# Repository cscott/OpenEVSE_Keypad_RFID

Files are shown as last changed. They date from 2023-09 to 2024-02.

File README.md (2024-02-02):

# OpenEVSE Capacitive keypad and RFID reader

Thing tracker at
https://cscott.github.io/thing-tracker/#/thing/c6539aa6-b8c7-4adf-a22c-1baba5bbef97

There is a [Hackaday page for this project].

Discussion in the OpenEVSE forum at
https://openev.freshdesk.com/support/discussions/topics/6000067515

## Description

This repository contains hardware design files for a capacitive
keypad and RFID reader for [OpenEVSE] hardware.

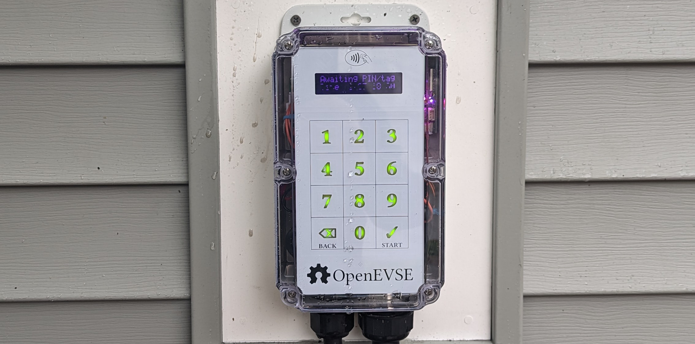
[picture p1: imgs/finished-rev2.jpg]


More details can be found on the
[Hackaday page for this project].

<br clear="both" />

## Instructions

### Step 1: Purchase components

You will need to purchase a new
[Polycase ML-58 enclosure](https://www.polycase.com/ml-58f), although
the only part we will need from it is the clear front cover.  (Perhaps
we can arrange a special purchase of just the cover if demand
warrants.)

You will also need to purchase or have the Keypad PCB fabricated.  The
KiCad design files are in the [`Keypad-Front`](./Keypad-Front)
subdirectory. It's a four-layer PCB, and I recommend white silkscreen
to avoid heating when in direct sun.  I used 1oz copper on a standard
1.6mm thick PCB.  I found that [JLCPCB](https://jlcpcb.com/) had
very reasonable prices.

I assume you also own an
[OpenEVSE Advanced Series](https://store.openevse.com/collections/all-products)
and have assembled it.

You will also need an LCD mount, which can be 3d printed.  You *might*
be able to reuse the one from your existing OpenEVSE device, but
you'll need to pry the glue off then cut down the top bar. It's
probably easier just to print a new one.

[`lcd-trim-more.stl`]

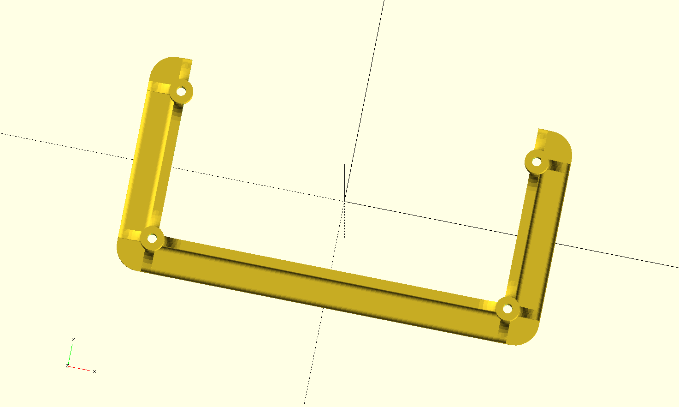
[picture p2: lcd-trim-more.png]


For compatibility with the latest OpenEVSE web interface, you will
also need to update the firmware on your main OpenEVSE controller
board.  This is out of scope for this guide, but you can find
instructions HERE.  It's a good thing to do between step 3 and 4
when you have your OpenEVSE charger disconnected and open.

### Step 2: Purchase or fabricate I2C cable

You will also need an I2C cable from the OpenEVSE Wifi board.  If you
have the latest-generation WiFi board, this will be a STEMMA-QT cable
(JST-SH, with 1.0mm pitch).  Older boards had an 8-pin JST-PH
connector (2.0mm pitch) and you will have to fabricate an adapter
yourself.

TODO: photos here

### Step 3: Remove cover from OpenEVSE

Unplug your OpenEVSE.  Don't try to do this with your OpenEVSE still
connected to mains power!

Remove the old printed blue cover from your OpenEVSE.  Disconnect
the cable leading from the OpenEVSE main board to the LCD display.

TODO: photo here.

### Step 4: Move the LCD module

Unscrew the LCD module from your old device and screw it onto the new
LCD mount.  You will then need to attach the new LCD mount to the
Keypad PCB, using the silkscreen as a guide.  I found that hot glue
worked well, but other adhesives are probably fine as well.

TODO: photo here

### Step 5: Mount the new PCB

You will now attach the Keypad PCB to the inside of your new clear
ML-58 enclosure cover.  I found that placing the board inside
the cover and then using generous drops of hot glue around the
screw bosses secured the Keypad PCB in a reversible manner, so that I
could still remove it if I needed to later.

TODO: photo here

If you're braver, a clear contact-sensitive adhesive tape (3M
makes a number of different types) would make a more permanent
bond.  Eliminating the air gap between the front cover and the
Keypad PCB is said to yield better performance from capacitive touch
sensors, but the hot-glue method has worked well enough for me.

### Step 5: Connect cables

You will need to connect two cables:

1. The LCD cable that you removed in step 3.

TODO: photo here

2. The I2C cable from step 2, from the OpenEVSE Wifi board to the
STEMMA-QT-compatible ports on the Keypad PCB.

TODO: photo here

### Step 6: Reattach the cover

Screw the cover back on the OpenEVSE!

TODO: photo here

### Step 7: Update OpenEVSE firmware

You'll need to reflash the OpenEVSE to the latest firmware.  The
good news is that you can do this over the web interface!

TODO: instructions here

### Step 8: Add some PINs and cards

TODO: instructions here

### Step 9: Optional improvements

The Keypad PCB also contains an MCP9808 temperature sensor and pads
for a DS3231MZ real-time clock.  Some older versions of the OpenEVSE
hardware contained an MCP9808 daisy-chained from the LCD module and
secured to the front cover.  If your hardware is like this, then
you can use the MCP9808 on the board by connecting the LCD display
to this port on the keypad PCB:

TODO: photo here

You should be able to use your existing cable, but if you have to
purchase or fabricate a new one, it's a STEMMA-QT compatible JST-SH
(1.0mm pitch) on the Keypad PCB side.  On my example, it was JST-PH
(2.0mm pitch) on the LCD side, and you can [buy an appropriate cable
from Adafruit](https://www.adafruit.com/product/4424).

Similarly, *newer* versions of the OpenEVSE hardware omit the
real-time clock which was present on the original OpenEVSE LCD modules.
The justification is that, with ubiquitous network connectivity,
you don't need to pay the steep price (~$10) for a clock chip when
instead you can just ask the network what time it is.

However, if you have intermittent network connectivity at your
installation site, you might want the peace of mind of knowing that
your usage timestamps will always be correct.  Because the RTC chip
is not cheap, it is not populated on the keypad PCB by default,
although all of its support components are present.  You can buy
an appropriate chip ([Digikey part link](https://www.digikey.com/en/products/detail/analog-devices-inc-maxim-integrated/DS3231MZ/2754396))
and battery connector ([Digikey part link](https://www.digikey.com/en/products/detail/mpd-memory-protection-devices/BC-2003-TR/5027929))
and hand-solder them onto the footprints provided.  While you've got
the soldering iron hot, you will most likely want to *remove* the
MCP9808 chip present on the Keypad PCB, since as far as I'm aware
all of the LCD modules *missing* the RTC *also* have the MCP9808
already present on the LCD board.  You don't want two MCP9808s trying
to talk on the same I2C bus.

After adding the RTC, you'd connect the I2C cable from the LCD
module to the Keypad PCB just as done for the MCP9808 above.

## Related

* [OpenEVSE] project
* [Hackaday page for this project]

## License

These designs are licensed under the [CC-BY-SA-4.0] like the original
OpenEVSE designs.

[OpenEVSE]: https://www.openevse.com/
[Hackaday page for this project]: https://hackaday.io/project/194656-openevse-capacitive-keypad-rfid
[`lcd-trim-more.stl`]: ./lcd-trim-more.stl
[CC-BY-SA-4.0]: https://spdx.org/licenses/CC-BY-SA-4.0.html

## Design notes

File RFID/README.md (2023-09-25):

Using
https://www.rfwireless-world.com/calculators/NFC-rectangular-antenna-calculator.html

99mm x 49mm (outer diam)
0.4mm track width, 0.4mm track gap
0.035mm track thickness (1oz copper)
2 turns
Fitting parameter E 1.65 ?

Inductance: 1.0055453920504143 uH
Equivelant conductor diameter: 0.13351167994874863 mm
Average length: 97.41314079732774 mm
Average width: 47.426996531511456 mm
-------------------
Tweaked:
45.6 mm x 98.8 mm
--------------
https://www.st.com/resource/en/application_note/cd00221490-how-to-design-a-13-56-mhz-customized-antenna-for-st25-nfc-rfid-tags-stmicroelectronics.pdf
https://www.nxp.com/docs/en/nxp/data-sheets/PN532_C1.pdf
https://www.nxp.com/docs/en/nxp/application-notes/153710.pdf
https://www.nxp.com/docs/en/nxp/application-notes/AN133910.pdf
https://www.nxp.com/products/rfid-nfc/nfc-hf/nfc-readers/nfc-integrated-solution:PN5321A3HN

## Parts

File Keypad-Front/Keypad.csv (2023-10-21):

Id | Designator | Footprint | Quantity | Designation | Supplier and ref
1 | TP12 | Touch_Pad_D1.0mm | 1 | KEY ENTER
2 | TP8 | Touch_Pad_D1.0mm | 1 | KEY 8
3 | TP7 | Touch_Pad_D1.0mm | 1 | KEY 7
4 | TP4 | Touch_Pad_D1.0mm | 1 | KEY 4
5 | TP9 | Touch_Pad_D1.0mm | 1 | KEY 9
6 | TP3 | Touch_Pad_D1.0mm | 1 | KEY 3
7 | TP5 | Touch_Pad_D1.0mm | 1 | KEY 5
8 | TP6 | Touch_Pad_D1.0mm | 1 | KEY 6
9 | TP11 | Touch_Pad_D1.0mm | 1 | KEY 0
10 | TP10 | Touch_Pad_D1.0mm | 1 | KEY BACK
11 | TP2 | Touch_Pad_D1.0mm | 1 | KEY 2
12 | TP1 | Touch_Pad_D1.0mm | 1 | KEY 1
13 | U4 | HVQFN-40-1EP_6x6mm_P0.5mm_EP4.1x4.1mm | 1 | PN5321A3HN_C1xx
14 | FB2,FB1 | R_0805_2012Metric_Pad1.20x1.40mm_HandSolder | 2 | FerriteBead_Small
15 | C3,C2 | C_0805_2012Metric_Pad1.18x1.45mm_HandSolder | 2 | 33pF
16 | D12,D1,D4,D8,D2,D11,D10,D3,D9,D5,D6,D7 | SunLED_3.2x2.8mm_ReverseMount | 12 | LED
17 | C1,C4 | C_0805_2012Metric_Pad1.18x1.45mm_HandSolder | 2 | 0.1uF
18 | Y3 | Crystal_SMD_TXC_7M-4Pin_3.2x2.5mm_HandSoldering | 1 | 27.12MHz
19 | R18,R17,R20 | R_0805_2012Metric_Pad1.20x1.40mm_HandSolder | 3 | 10k
20 | R6,R1,R3,R4,R11,R10,R16,R7,R8,R5,R12,R9,R2 | R_1206_3216Metric_Pad1.30x1.75mm_HandSolder | 13 | 100
21 | U5 | MSOP-8_3x3mm_P0.65mm | 1 | MCP9808_MSOP
22 | C9,C10,C14 | C_0805_2012Metric_Pad1.18x1.45mm_HandSolder | 3 | 10uF
23 | U3 | QFN-32-1EP_5x5mm_P0.5mm_EP3.3x3.3mm_ThermalVias | 1 | CAP1214
24 | JP1 | SolderJumper-3_P1.3mm_Bridged12_Pad1.0x1.5mm | 1 | SEL0
25 | R28,R29,R15,R30,R27 | R_0805_2012Metric_Pad1.20x1.40mm_HandSolder | 5 | 0
26 | R21,R22 | R_0805_2012Metric_Pad1.20x1.40mm_HandSolder | 2 | 1.5
27 | U1 | SOIC-8_3.9x4.9mm_P1.27mm | 1 | DS3231MZ
28 | J7 | JST-SH-4-VERT-SMD | 1 | TOUCH QWIIC
29 | R26 | R_0805_2012Metric_Pad1.20x1.40mm_HandSolder | 1 | 1.0k
30 | C13,C6,C7,C15,C26,C8,C11 | C_0805_2012Metric_Pad1.18x1.45mm_HandSolder | 7 | .1uF
31 | R25 | R_0805_2012Metric_Pad1.20x1.40mm_HandSolder | 1 | 2.7k
32 | BT1 | BatteryHolder_MPD_BC2003_1x2032 | 1 | Battery_Cell
33 | C18,C12,C24,C23 | C_0805_2012Metric_Pad1.18x1.45mm_HandSolder | 4 | N/C
34 | L1,L2 | L_0805_2012Metric_Pad1.15x1.40mm_HandSolder | 2 | 560nH
35 | C5 | C_0805_2012Metric_Pad1.18x1.45mm_HandSolder | 1 | 47pF
36 | R13,R19,R14 | R_0805_2012Metric_Pad1.20x1.40mm_HandSolder | 3 | 4.7k
37 | C19,C20 | C_0805_2012Metric_Pad1.18x1.45mm_HandSolder | 2 | 22pF
38 | C16,C17 | C_0805_2012Metric_Pad1.18x1.45mm_HandSolder | 2 | 220pF
39 | JP2 | SolderJumper-3_P1.3mm_Bridged12_Pad1.0x1.5mm | 1 | SEL1
40 | R23,R24 | SolderJumper-2_P1.3mm_Bridged_Pad1.0x1.5mm | 2 | N/C
41 | C21,C22 | C_0805_2012Metric_Pad1.18x1.45mm_HandSolder | 2 | 100pF
42 | J6 | JST-SH-4-VERT-SMD | 1 | EXP QWIIC
43 | C25 | C_0805_2012Metric_Pad1.18x1.45mm_HandSolder | 1 | 1000pF
44 | J1 | JST-SH-4-VERT-SMD | 1 | RTC STEMMA QT
45 | BZ1 | XDCR_SMT-1220-TW-R | 1 | Buzzer

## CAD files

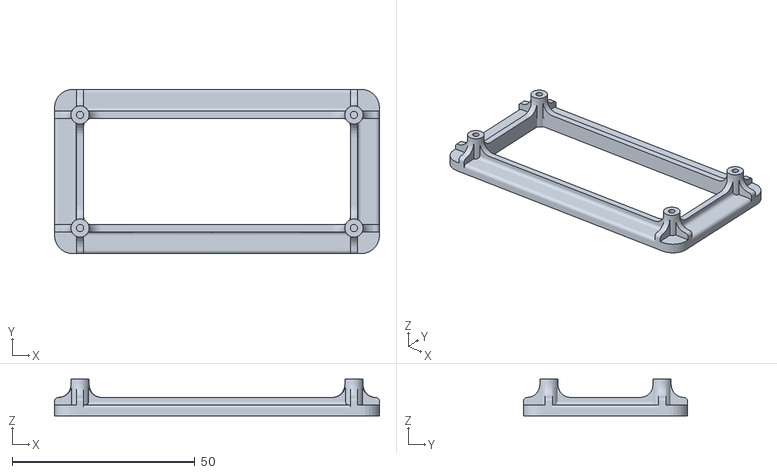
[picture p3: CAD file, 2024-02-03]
LCD_fixed.stl
89.0 x 45.0 x 10.0

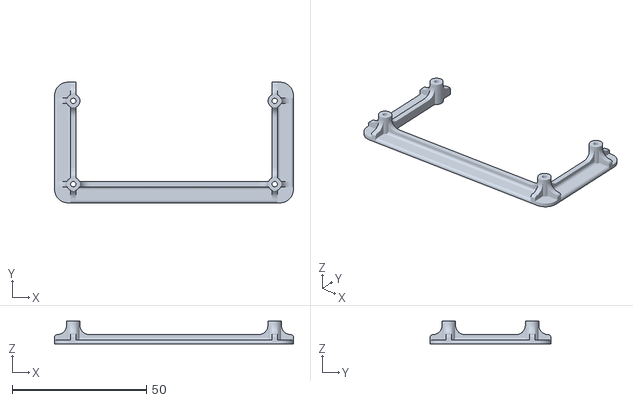
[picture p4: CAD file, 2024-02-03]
lcd-trim-more.stl
89.0 x 45.0 x 8.40

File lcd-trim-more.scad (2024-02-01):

cutoff=1.6;
difference() {
  intersection() {
    import("LCD_fixed.stl", convexity=5);
    translate([0,0,50 + cutoff]) cube([1000,1000,100], center=true);
  }
  difference() {
   translate([0,25,0]) cube([73,50,30], center=true);
   for (i=[-1,1]) {
     translate([i*75/2,15.5,0]) cylinder(d=5, h=30, $fn=20, center=true);
   }
  }
  for (i=[-1,1]) {
  for (j=[-1,1]) {
    translate([i*75/2,j*15.5,0]) cylinder(d=2, h=30, $fn=20, center=true);
  }
  }
}

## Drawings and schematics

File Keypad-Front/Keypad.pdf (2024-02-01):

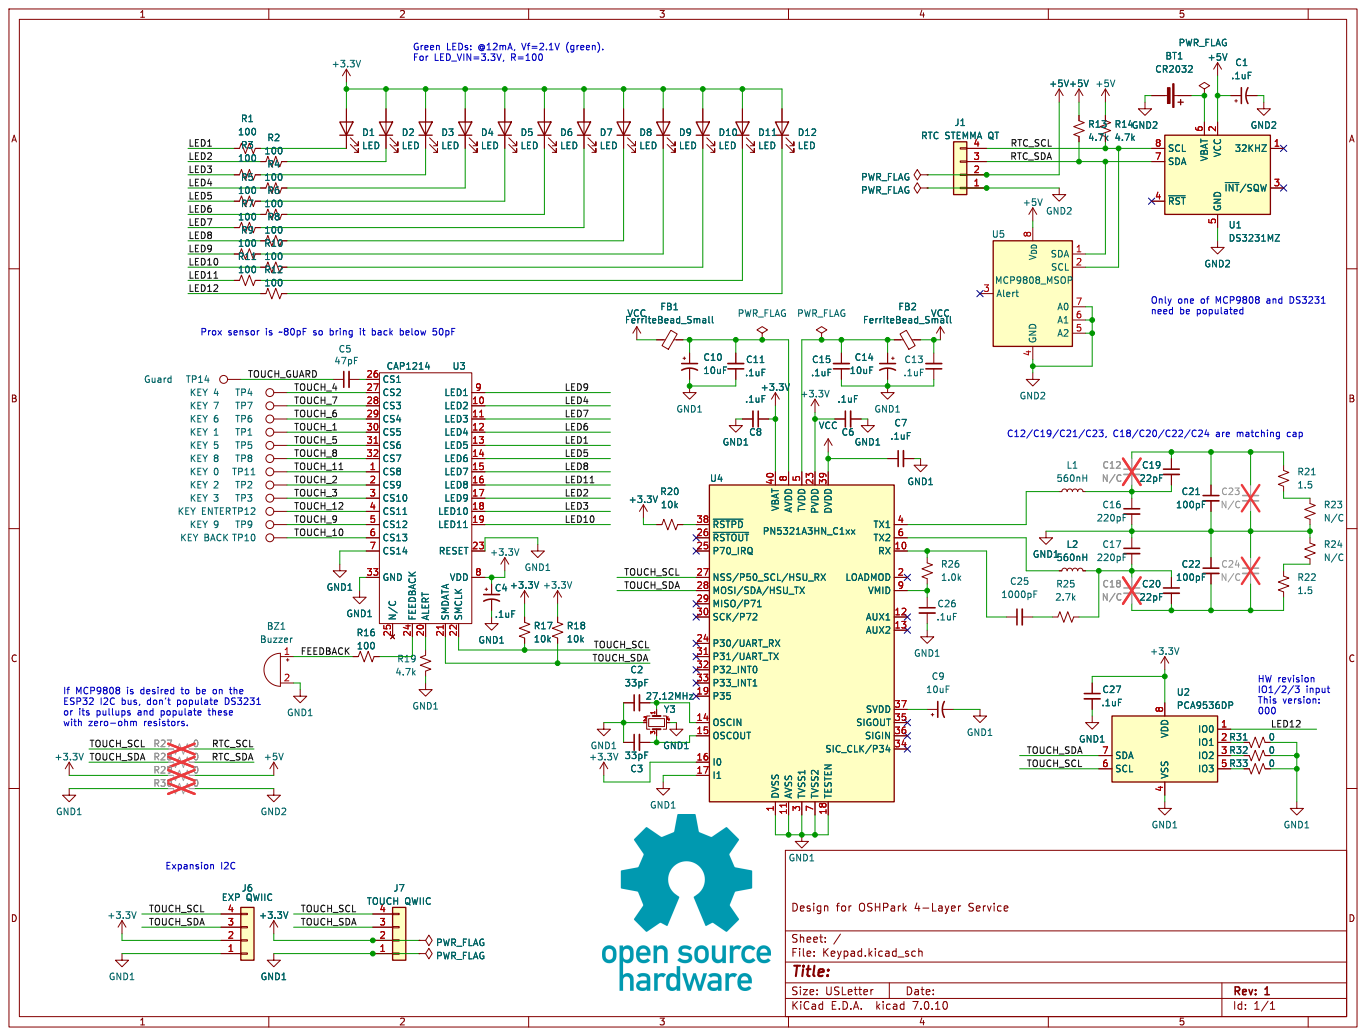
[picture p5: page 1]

3 SCK/P72 30 P31/UART_TX 31 P32_INT0 32 P33_INT1 33 SIC_CLK/P34 34 SIGOUT 35 SIGIN 36 SVDD 37 ~{RSTPD} 38 DVDD 39 TX1 4 VBAT 40 TVDD

1 RX 10 AVSS 11 AUX1 12 AUX2 13 OSCIN 14 OSCOUT 15

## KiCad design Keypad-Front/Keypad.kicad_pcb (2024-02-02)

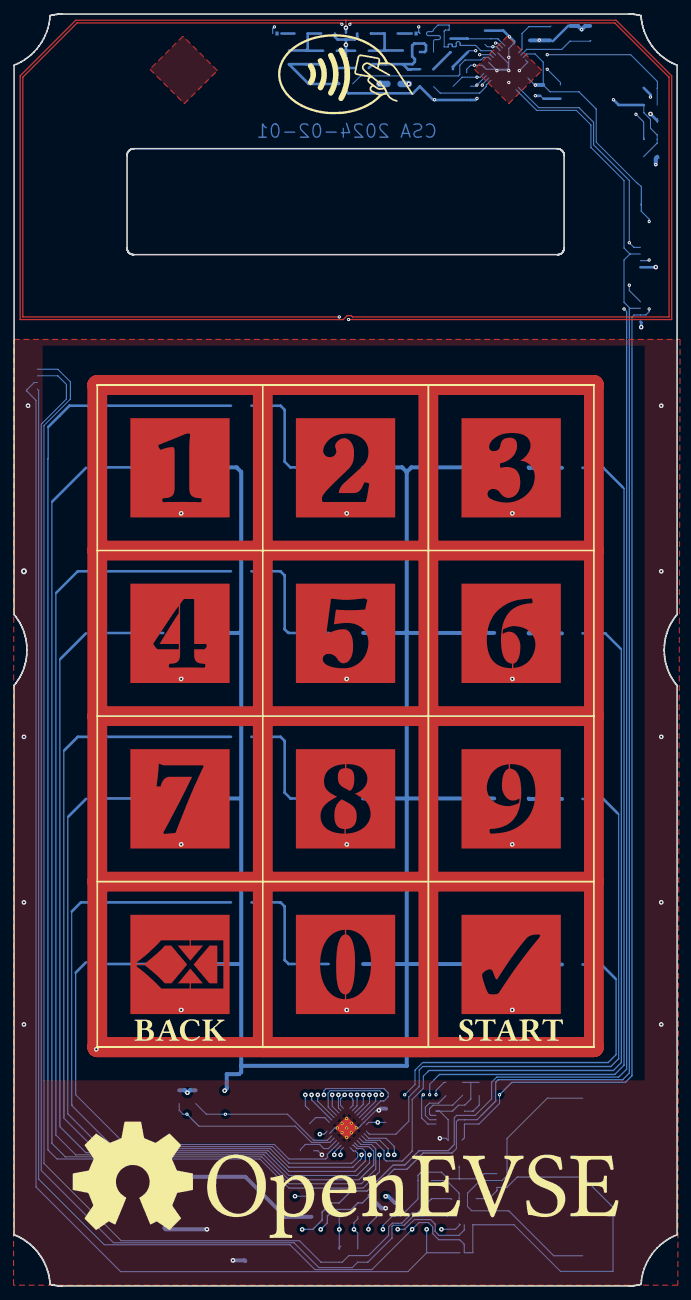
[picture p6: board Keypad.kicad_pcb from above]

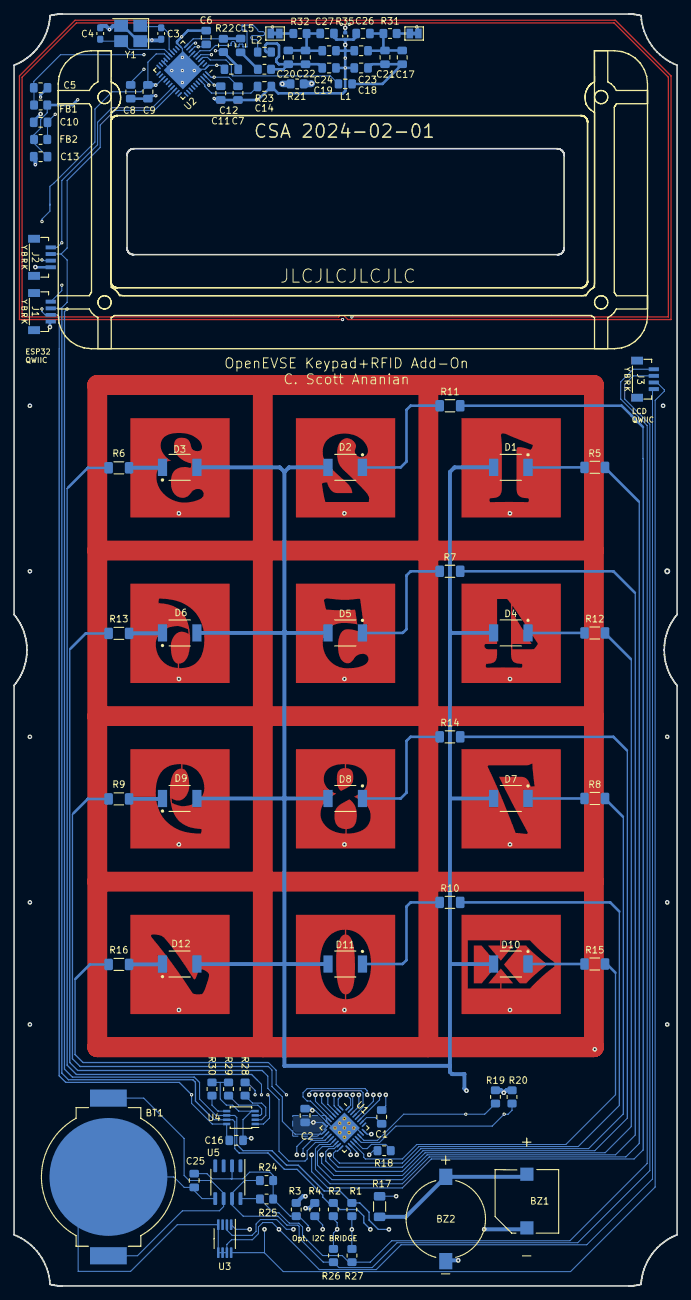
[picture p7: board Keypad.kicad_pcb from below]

Board: 4 copper layers, 100.1 x 192.1 mm, 103 parts (90 on the bottom side), 74 nets.

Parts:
BT1: CR2032; BatteryHolder_MPD_BC2003_1x2032
BZ1: FUET-9650B-3V
BZ2: PUI SMT-1220-TW-R; XDCR_SMT-1220-TW-R
C1: 47pF; C_0805_2012Metric_Pad1.18x1.45mm_HandSolder
C2, C6, C7, C8, C9, C11, C12, C13, C16, C25: .1uF; C_0805_2012Metric_Pad1.18x1.45mm_HandSolder
C3, C4: 33pF; C_0603_1608Metric_Pad1.08x0.95mm_HandSolder
C5, C10, C14: 10uF; C_0805_2012Metric_Pad1.18x1.45mm_HandSolder
C15: 1000pF; C_0805_2012Metric_Pad1.18x1.45mm_HandSolder
C17, C20, C26, C27: N/C; C_0805_2012Metric_Pad1.18x1.45mm_HandSolder
C18, C19: 220pF; C_0805_2012Metric_Pad1.18x1.45mm_HandSolder
C21, C22: 22pF; C_0805_2012Metric_Pad1.18x1.45mm_HandSolder
C23, C24: 100pF; C_0805_2012Metric_Pad1.18x1.45mm_HandSolder
D1, D2, D3, D4, D5, D6, D7, D8, D9, D10, D11, D12: SunLED XZVG45WT-9; SunLED_3.2x2.8mm_ReverseMount
FB1, FB2: Laird MI0805J102R-10; R_0805_2012Metric_Pad1.20x1.40mm_HandSolder
J1: EXP QWIIC; JST-SH-4-VERT-SMD
J2: TOUCH QWIIC; JST-SH-4-VERT-SMD
J3: RTC STEMMA QT; JST-SH-4-VERT-SMD
L1, L2: 560nH; L_0805_2012Metric_Pad1.15x1.40mm_HandSolder
R1, R2, R3, R4, R26, R27: 0; R_0805_2012Metric_Pad1.20x1.40mm_HandSolder
R5, R6, R7, R8, R9, R10, R11, R12, R13, R14, R15, R16, R17: 100; R_1206_3216Metric_Pad1.30x1.75mm_HandSolder
R18, R24, R25: 4.7k; R_0805_2012Metric_Pad1.20x1.40mm_HandSolder
R19, R20, R21: 10k; R_0805_2012Metric_Pad1.20x1.40mm_HandSolder
R22, R28, R29, R30: 1k; R_0805_2012Metric_Pad1.20x1.40mm_HandSolder
R23: 2.7k; R_0805_2012Metric_Pad1.20x1.40mm_HandSolder
R31, R32: 1.5; R_0805_2012Metric_Pad1.20x1.40mm_HandSolder
R33, R34: N/C; SolderJumper-2_P1.3mm_Bridged_Pad1.0x1.5mm
R35: 0; R_0402_1005Metric
TP1: Guard; Touch_Pad_D1.0mm
TP2: KEY 4; Touch_Pad_D1.0mm
TP3: KEY 7; Touch_Pad_D1.0mm
TP4: KEY 6; Touch_Pad_D1.0mm
TP5: KEY 1; Touch_Pad_D1.0mm
TP6: KEY 5; Touch_Pad_D1.0mm
TP7: KEY 8; Touch_Pad_D1.0mm
TP8: KEY 0; Touch_Pad_D1.0mm
TP9: KEY 2; Touch_Pad_D1.0mm
TP10: KEY 3; Touch_Pad_D1.0mm
TP11: KEY ENTER; Touch_Pad_D1.0mm
TP12: KEY 9; Touch_Pad_D1.0mm
TP13: KEY BACK; Touch_Pad_D1.0mm
U1: CAP1214; QFN-32-1EP_5x5mm_P0.5mm_EP3.3x3.3mm_ThermalVias
U2: PN5321A3HN_C1xx; HVQFN-40-1EP_6x6mm_P0.5mm_EP4.1x4.1mm
U3: MCP9808_MSOP; MSOP-8_3x3mm_P0.65mm
U4: PCA9536DP; TSSOP-8_3x3mm_P0.65mm
U5: DS3231MZ; SOIC-8_3.9x4.9mm_P1.27mm
Y1: 27.12MHz; Crystal_SMD_TXC_7M-4Pin_3.2x2.5mm_HandSoldering

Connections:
+3.3V: C2.1, C7.1, C9.1, C16.1, D1.2 (A), D2.2 (A), D3.2 (A), D4.2 (A), D5.2 (A), D6.2 (A), D7.2 (A), D8.2 (A), D9.2 (A), D10.2 (A), D11.2 (A), D12.2 (A), J1.2, J2.2, R3.1, R19.1, R20.1, R21.1, R28.2, U1.8 (VDD), U2.16 (I0), U2.23 (PVDD), U2.40 (VBAT), U4.8 (VDD)
+5V: C25.1, J3.2, R3.2, R24.1, R25.1, U3.8 (V_{DD}), U5.2 (VCC)
/FEEDBACK: BZ1.1 (+), BZ2.1 (+), R17.1
/FEED_N: C19.2, C20.1, C22.1, L2.2, R23.1
/FEED_P: C17.2, C18.1, C21.2, L1.2
/LED1: R5.1, U1.13 (LED5)
/LED2: R11.1, U1.17 (LED9)
/LED3: R6.1, U1.18 (LED10)
/LED4: R12.1, U1.10 (LED2)
/LED5: R7.1, U1.14 (LED6)
/LED6: R13.1, U1.12 (LED4)
/LED7: R8.1, U1.11 (LED3)
/LED8: R14.1, U1.15 (LED7)
/LED9: R9.1, U1.9 (LED1)
/LED10: R15.1, U1.19 (LED11)
/LED11: R10.1, U1.16 (LED8)
/LED12: R16.1, U4.1 (IO0)
/RTC_SCL: J3.4, R25.2, R27.1, U5.8 (SCL)
/RTC_SDA: J3.3, R24.2, R26.1, U5.7 (SDA)
/TEMP_SCL: R1.2, R27.2, U3.2 (SCL)
/TEMP_SDA: R2.2, R26.2, U3.1 (SDA)
/TOUCH_1: TP5.1, U1.30 (CS5)
/TOUCH_2: TP9.1, U1.2 (CS9)
/TOUCH_3: TP10.1, U1.3 (CS10)
/TOUCH_4: TP2.1, U1.27 (CS2)
/TOUCH_5: TP6.1, U1.31 (CS6)
/TOUCH_6: TP4.1, U1.29 (CS4)
/TOUCH_7: TP3.1, U1.28 (CS3)
/TOUCH_8: TP7.1, U1.32 (CS7)
/TOUCH_9: TP12.1, U1.5 (CS12)
/TOUCH_10: TP13.1, U1.6 (CS13)
/TOUCH_11: TP8.1, U1.1 (CS8)
/TOUCH_12: TP11.1, U1.4 (CS11)
/TOUCH_GUARD: C1.1, TP1.1
/TOUCH_SCL: J1.4, J2.4, R1.1, R19.2, U1.22 (SMCLK), U2.27 (NSS/P50_SCL/HSU_RX), U4.6 (SCL)
/TOUCH_SDA: J1.3, J2.3, R2.1, R20.2, U1.21 (SMDATA), U2.28 (MOSI/SDA/HSU_TX), U4.7 (SDA)
/TX_N: L2.1, U2.6 (TX2)
/TX_P: L1.1, U2.4 (TX1)
GND1: BZ1.2 (-), BZ2.2 (-), C2.2, C3.1, C4.1, C5.2, C6.1, C7.2, C8.1, C9.2, C10.2, C11.2, C12.2, C13.1, C14.2, C16.2, C18.2, C19.1, C23.2, C24.1, C26.2, C27.1, J1.1, J2.1, R4.1, R18.2, R29.2, R30.2, R35.1, U1.7 (CS14), U1.23 (RESET), U1.33 (GND), U2.1 (DVSS), U2.3 (TVSS1), U2.7 (TVSS2), U2.11 (AVSS), U2.17 (I1), U2.18 (TESTEN), U2.41 (AVSS), U4.4 (VSS), Y1.2, Y1.4
GND2: BT1.2 (-), C25.2, J3.1, R4.2, U3.4 (GND), U3.5 (A2), U3.6 (A1), U3.7 (A0), U5.5 (GND)
unnamed: BT1.1 (+), U5.6 (VBAT)
unnamed: C15.2, R23.2
unnamed: C17.1, C21.1, C23.1, C26.1, R31.2
unnamed: C20.2, C22.2, C24.2, C27.2, R32.1
unnamed: D1.1 (K), R5.2
unnamed: D2.1 (K), R11.2
unnamed: D3.1 (K), R6.2
unnamed: D4.1 (K), R12.2
unnamed: D5.1 (K), R7.2
unnamed: D6.1 (K), R13.2
unnamed: D7.1 (K), R8.2
unnamed: D8.1 (K), R14.2
unnamed: D9.1 (K), R9.2
unnamed: D10.1 (K), R15.2
unnamed: D11.1 (K), R10.2
unnamed: D12.1 (K), R16.2
unnamed: R31.1, R33.2
unnamed: R32.2, R34.1
unnamed: R33.1, R34.2, R35.2
unnamed: R18.1, U1.20 (ALERT)
unnamed: C1.2, U1.26 (CS1)
unnamed: R17.2, U1.24 (FEEDBACK)
unnamed: C5.1, C6.2, FB1.2, U2.8 (AVDD)
unnamed: C3.2, U2.14 (OSCIN), Y1.1
unnamed: C4.2, U2.15 (OSCOUT), Y1.3
unnamed: C15.1, R22.2, U2.10 (RX)
unnamed: C14.1, U2.37 (SVDD)
unnamed: C8.2, C10.1, FB2.2, U2.5 (TVDD)
unnamed: C12.1, R22.1, U2.9 (VMID)
unnamed: R21.2, U2.38 (~RSTPD)
unnamed: R28.1, U4.2 (IO1)
unnamed: R29.1, U4.3 (IO2)
unnamed: R30.1, U4.5 (IO3)
VCC: C11.1, C13.2, FB1.1, FB2.1, U2.39 (DVDD)

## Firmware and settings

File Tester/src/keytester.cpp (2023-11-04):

#if defined(KEYTESTER)

#define RTCTEST 1
#define TEMPTEST 1
#define RFIDTEST 1
//#define PROXTEST 1
//#define LEDTEST 1

#define BRIGHT_PAD 1
#define LONG_WAIT_AFTER_INIT

// Note that Capacitive sensing is significantly more sensitive when the
// system has a robust earth ground, which is the case when the OpenEVSE
// is installed but may not be the case if attempting to calibrate on a
// bench.

// Sensitivity is 0-15 with 15 being max sensitivity; each step is 2x
// sensitivity of previous step.
#define PROX_SENSITIVITY 15 /* when installed is 13 */
#define KEY_SENSITIVITY 14 /* when installed is 13 */

#ifdef BRIGHT_PAD
# define POLARITY_AWAKE 0xFF
# define POLARITY_ASLEEP 0x00
#else
# define POLARITY_AWAKE 0x00
# define POLARITY_ASLEEP 0xFF
#endif

#include "Arduino.h"
#include <Wire.h>
#include <AsyncDelay.h>

#include <ESP8266WiFi.h>
#include <WiFiClient.h>
#include <ESP8266mDNS.h>
#include <ArduinoOTA.h>

// includes for OLED display
#include <SPI.h>
#include <Wire.h>
#include <Adafruit_GFX.h>
#include <Adafruit_SH110X.h>

#include "cap1214-reg.h"
#include "config.h"
#define MDNS_NAME "keytester"

#define PCA9536_I2C_ADDR     0x41
#define PCA9536_REG_INPUT    0x00
#define PCA9536_REG_OUTPUT   0x01
#define PCA9536_REG_POLARITY 0x02
#define PCA9536_REG_CONFIG   0x03

#ifdef RFIDTEST
#include "Adafruit_PN532.h"
Adafruit_PN532 rfid(-1, -1, &Wire);
bool rfid_good = false;
#endif

#ifdef TEMPTEST
#include "Adafruit_MCP9808.h"
Adafruit_MCP9808 tempsensor = Adafruit_MCP9808();
bool tempsensor_good = false;
#endif

#ifdef RTCTEST
#include "RTClib.h"
RTC_DS3231 rtc;
char daysOfTheWeek[7][12] = {
  "Sun", "Mon", "Tue", "Wed", "Thu", "Fri", "Sat"
};
bool rtc_good = false;
#endif /* RTCTEST */
bool cap_good = false;
bool is_awake = true;
bool keypad_hw_v2 = false;
uint8_t polarity = 0;

// Configuration of OLED display
Adafruit_SH1107 display = Adafruit_SH1107(64, 128, &Wire);

// OLED FeatherWing buttons map to different pins depending on board:
#define BUTTON_A  0
#define BUTTON_B 16
#define BUTTON_C  2

// Other config
#define LED_GPIO 0
#define LED_OFF 1 // active low
#define LED_ON  0 // active low

AsyncDelay updateDelay = AsyncDelay(250, AsyncDelay::MILLIS);
AsyncDelay proxDelay = AsyncDelay(5000, AsyncDelay::MILLIS);
bool blinkWasOn = false;
bool mdns_success;

bool pca9536_write(uint8_t regno, uint8_t val) {
  Wire.beginTransmission(PCA9536_I2C_ADDR);
  Wire.write(regno);
  Wire.write(val);
  uint8_t status = Wire.endTransmission();
  if (status != 0) {
    return false;
  }
  return true;
}

bool pca9536_read(uint8_t regno, uint8_t *val) {
    Wire.beginTransmission(PCA9536_I2C_ADDR);
    Wire.write(regno);
    uint8_t status = Wire.endTransmission();
    if (status != 0) {
        return false;
    }
    uint8_t nBytes = Wire.requestFrom(PCA9536_I2C_ADDR, 1);
    if (nBytes == 0) {
        return false;
    }
    *val = Wire.read();
    return true;
}

int read_keypad_version() {
  // Configure to all inputs (also implicitly check to see whether it's present)
  if (!pca9536_write(PCA9536_REG_CONFIG, 0xFF)) { goto failed; }
  if (!pca9536_write(PCA9536_REG_POLARITY, 0x00)) { goto failed; }
  // Read the version pins!
  uint8_t version;
  if (!pca9536_read(PCA9536_REG_INPUT, &version)) { goto failed; }
  if ((version & 0x0E) == 0) {
    // this is version 1! First pin configure for output
    if (!pca9536_write(PCA9536_REG_OUTPUT, 0x01)) { goto failed; }
    if (!pca9536_write(PCA9536_REG_CONFIG, 0xFE)) { goto failed; }
    return 2; // Keypad HW v2
  }
  // Fall through -- this is an unrecognized version
 failed:
  return 1; // Keypad v1 didn't have a PCA9536
}

bool cap1214_write(uint8_t regno, uint8_t val) {
  Wire.beginTransmission(CAP1214_I2C_ADDR);
  Wire.write(regno);
  Wire.write(val);
  uint8_t status = Wire.endTransmission();
  if (status != 0) {
    return false;
  }
  return true;
}

bool cap1214_read(uint8_t regno, uint8_t *val) {
    Wire.beginTransmission(CAP1214_I2C_ADDR);
    Wire.write(regno);
    uint8_t status = Wire.endTransmission();
    if (status != 0) {
        return false;
    }
    uint8_t nBytes = Wire.requestFrom(CAP1214_I2C_ADDR, 1);
    if (nBytes == 0) {
        return false;
    }
    *val = Wire.read();
    return true;
}

bool cap1214_init(void) {
  uint8_t vendor_id, product_id, revision, build_rev;
  delay(20); // at least 20ms (tCOMM)
  if (!cap1214_read(CAP1214_REG_VENDOR_ID, &vendor_id)) { goto failed; }
  if (vendor_id != 0x5D) { goto failed; }
  if (!cap1214_read(CAP1214_REG_PRODUCT_ID, &product_id)) { goto failed; }
  if (product_id != 0x5A) { goto failed; }
  if (!cap1214_read(CAP1214_REG_REVISION, &revision)) { goto failed; }
  if (revision != 0x80) { goto failed; }
  if (!cap1214_read(CAP1214_REG_BUILD_REVISION, &build_rev)) { goto failed; }
  if (build_rev != 0x10) { goto failed; }
  // Activate LEDs and scanning
  cap1214_write(CAP1214_REG_MAIN_STATUS, 0x00);
  cap1214_write(CAP1214_REG_CONFIGURATION, 0x2A);// enable recal on grouped sens, disable repeat rate
  cap1214_write(CAP1214_REG_CONFIGURATION_2, 0x02); // *not* VOL_UP_DOWN
  cap1214_write(CAP1214_REG_GROUP_CONFIGURATION_1, 0x40); // zero out M_PRESS (CS8)
  cap1214_write(CAP1214_REG_SENSOR_ENABLE, 0xFF);
  cap1214_write(CAP1214_REG_GROUPED_CHANNEL_SENSOR_ENABLE, 0x3F); // disable CS14
  // Increase general sensitivity
  cap1214_write(CAP1214_REG_DATA_SENSITIVITY, 0x0F + 16*(15-KEY_SENSITIVITY)); // 64x sensitivity
  cap1214_write(CAP1214_REG_PROXIMITY_CONTROL, 0x80 + (15-PROX_SENSITIVITY)); // CS1 is prox, max sens
  // allow independent configuration of CS1 threshold
  cap1214_write(CAP1214_REG_RECALIBRATION_CONFIGURATION, 0x13); // !BUT_LD_TH
  // 256ms, 2kHz 110 01000
  cap1214_write(CAP1214_REG_FEEDBACK_CONFIGURATION, 0xC8); // 256ms, 2kHz
  // Everything triggers feedback, but CS1, CS8, and CS14
  // (CS8 has a weird press-and-hold misfeatures that triggers feedback
  // before the actual press is registered in the queue.)
  cap1214_write(CAP1214_REG_FEEDBACK_CHANNEL_CONFIGURATION_1, 0x7E);
  cap1214_write(CAP1214_REG_FEEDBACK_CHANNEL_CONFIGURATION_2, 0x3E);
  // Link the sensor LEDs CS2-CS7
  // - excluding CS1 because it is used for proximity
  // - excluding UP_DOWN_LINK
  if (keypad_hw_v2) {
    cap1214_write(CAP1214_REG_SENSOR_LED_LINKING, 0x7E);
  } else {
    // In v1 hardware, also:
    // - excluding CS4 for which we need manual control because it is paired
    cap1214_write(CAP1214_REG_SENSOR_LED_LINKING, 0x76);
  }
  // LED/GPIO pins are outputs!
  cap1214_write(CAP1214_REG_LED_GPIO_DIRECTION, 0xFF); // LED1-LED8 = output
  // flip polarity of all LEDs (normally off, to keep power low)
  polarity = POLARITY_ASLEEP;
  cap1214_write(CAP1214_REG_LED_POLARITY_1, polarity);
  cap1214_write(CAP1214_REG_LED_POLARITY_2, polarity);

  // disable multiple touch suppression (since PROX aka CS1 sets it off)
  cap1214_write(CAP1214_REG_MULTIPLE_PRESS_CONFIGURATION, 0x00);
#if 1
  // Improve responsiveness: by default we need 3 readings over threshold;
  // change to 1 to make things a bit snappier.
  cap1214_write(CAP1214_REG_QUEUE_CONTROL, 0x01);
#else
  // Reducing sample time by 50% doesn't seem to have the same effect
  // (probably because we're dominated by prox sampling time?)
  cap1214_write(CAP1214_REG_QUEUE_CONTROL, 0x02);
  cap1214_write(CAP1214_REG_SAMPLING_CHANNEL_SELECT, 0xFF);
  cap1214_write(CAP1214_REG_SAMPLING_CONFIGURATION, 0x01); // 1.28ms sampling time
#endif

#ifdef PROXTEST
  // disable all except for CS1 (prox)
  cap1214_write(CAP1214_REG_SENSOR_ENABLE, 0x01);
  cap1214_write(CAP1214_REG_PROXIMITY_CONTROL, 0x88);
  cap1214_write(CAP1214_REG_FEEDBACK_CHANNEL_CONFIGURATION_1, 0x01);
  cap1214_write(CAP1214_REG_FEEDBACK_CHANNEL_CONFIGURATION_2, 0x00);
  cap1214_write(CAP1214_REG_DATA_SENSITIVITY, 0x1F); // 8x sensitivity
#endif

#ifdef LEDTEST
  cap1214_write(CAP1214_REG_SENSOR_LED_LINKING, 0x00);
  for (uint8_t i=0; i<8; i++) {
    cap1214_write(CAP1214_REG_LED_OUTPUT_CONTROL_1, 1<<i);
    cap1214_write(CAP1214_REG_FEEDBACK_ONESHOT, 0xFF);
    delay(1000);
  }
  cap1214_write(CAP1214_REG_LED_OUTPUT_CONTROL_1, 0);
  for (uint8_t i=0; i<3; i++) {
    cap1214_write(CAP1214_REG_LED_OUTPUT_CONTROL_2, 1<<i);
    cap1214_write(CAP1214_REG_FEEDBACK_ONESHOT, 0xFF);
    delay(1000);
  }
  cap1214_write(CAP1214_REG_LED_OUTPUT_CONTROL_2, 0);
  cap1214_write(CAP1214_REG_SENSOR_LED_LINKING, 0x7E);
#endif

  // recalibrate all
  //cap1214_write(CAP1214_REG_DIGITAL_RECALIBRATION, 0xFF);
  return true;

 failed:
  return false;
}

uint16_t cap1214_read_buttons(bool clear = true) {
  uint8_t st1 = 0, st2 = 0, st3 = 0;
  cap1214_read(CAP1214_REG_BUTTON_STATUS_1, &st1);
  cap1214_read(CAP1214_REG_BUTTON_STATUS_2, &st2);
  cap1214_read(CAP1214_REG_GROUP_STATUS, &st3); // clears TAP
  if (clear) {
    // clear the latched button status by clearing INT!
    cap1214_write(CAP1214_REG_MAIN_STATUS, 0x00);
  }

  // merge
  uint16_t merged = (st1 & 0x3F); // zero out UP & DOWN
  merged |= (((uint16_t)st2) << 6); // Add in high order bits at the right place
  // account for tap and hold logic on CS8 (CS14 is unused)
  if (st3 & 0xF) { merged |= 0x80; }

#define merged_cs(x) (merged & (((uint16_t)1)<<(x-1)))
  // manually set feedback pins for CS8-CS13
  // CS8/9/10 -> LED8/9/10
  uint8_t led1 = 0, led2 = 0, led3 = 0;
  static bool saw_cs8 = false;
  if (merged_cs(8)) { // CS8 (touch 11, key 0)
    led1 |= 0x80;
    // Need to manually trigger feedback, because if we link this automatically
    // feedback will be triggered for touches too short to actually register
    // in the button queue.
    if (!saw_cs8) {
      cap1214_write(CAP1214_REG_FEEDBACK_ONESHOT, 0xFF);
      saw_cs8 = true;
    }
  } else {
    saw_cs8 = false;
  }
  if (merged_cs(9)) { // CS9 (touch 2)
    led2 |= 0x01; // LED 9
  }
  if (merged_cs(10)) { // CS10 (touch 3)
    led2 |= 0x02; // LED 10
  }
  if (keypad_hw_v2) {
    // CS11 & CS13 -> LED11/LED12 (expansion)
    if (merged_cs(13)) { // CS13 (touch 10, key backspace)
      led2 |= 0x04; // LED 11
    }
    if (merged_cs(11)) { // CS11 (touch 12, key enter)
      led3 |= 0x01; // LED 12
    }
  } else {
    // CS4 & CS11 -> LED4
    if (merged_cs(4)) { // CS4 (touch 10, key backspace)
      led1 |= 0x08; // LED 4
    }
    if (merged_cs(11)) { // CS11 (touch 12, key enter)
      led1 |= 0x08; // LED 4
    }
    // CS13 -> LED11
    if (merged_cs(13)) { // CS13 (touch 6)
      led2 |= 0x04;
    }
  }
  // CS12 -> LED1
  if (merged_cs(12)) { // CS12 (touch 9)
    led1 |= 0x01; // LED 1
  }
#undef merged_cs
  // Update LED OUTPUT CONTROL if necessary
  // last_* initialized to bogus values to force an initial update
  static uint8_t last_led1 = 0xFF, last_led2 = 0xFF, last_led3 = 0xFF;
  static uint8_t last_polarity = 0x55;
  if (led1 != last_led1) {
    cap1214_write(CAP1214_REG_LED_OUTPUT_CONTROL_1, led1);
    last_led1 = led1;
  }
  if (led2 != last_led2) {
    cap1214_write(CAP1214_REG_LED_OUTPUT_CONTROL_2, led2);
    last_led2 = led2;
  }
  if (keypad_hw_v2 && (led3 != last_led3 || polarity != last_polarity)) {
    pca9536_write(PCA9536_REG_OUTPUT, led3 ^ (~polarity));
    last_led3 = led3;
  }
  if (polarity != last_polarity) {
    cap1214_write(CAP1214_REG_LED_POLARITY_1, polarity);
    cap1214_write(CAP1214_REG_LED_POLARITY_2, polarity);
    last_polarity = polarity;
  }
  return merged;
}

void cap1214_read_key(char *key, bool *prox) {
  uint16_t st = cap1214_read_buttons();
  *prox = (st & 1);
  *key = 0;
  uint16_t mask;
  const char *cp = keypad_hw_v2 ?
    "476158023\r9\b" :
    "47\b158023\r96";
  for (mask=2; *cp; cp++, mask<<=1) {
    if (st&mask) {
      *key = *cp;
      return;
    }
  }
}

void normalText() {
  display.setTextColor(SH110X_WHITE, SH110X_BLACK);
}

void invertText() {
  display.setTextColor(SH110X_BLACK, SH110X_WHITE);
}

void maybeInvertText(bool maybe) {
  if (maybe) invertText(); else normalText();
}

void printHex(uint8_t num) {
    char buf[3];
    snprintf(buf, sizeof(buf), "%02X", (int)num);
    display.print(buf);
}

void updateDisplay() {
  display.clearDisplay();
  display.setCursor(0,0);
  display.setTextSize(1);
#ifdef PROXTEST
#define SCALE 8
  uint8_t uval;
  cap1214_read(CAP1214_REG_SENSOR_1_DELTA_COUNT, &uval);
  printHex(uval);
  int8_t val = (int8_t)uval;
  display.print("|");
  for (int i=-SCALE; i<0; i++) {
    display.print(val > 0 || ((i*0x80/SCALE) < val) ? " " : "-");
  }
  display.print("|");
  for (int i=0; i<SCALE; i++) {
    display.print(val < 0 || ((i*0x80/SCALE) > val) ? " " : "+");
  }
  display.print("|");
#else
  invertText();
  display.println("Keypad tester");
  normalText();
#if 0
  display.print("IP: ");
  display.println(WiFi.localIP());
  if (mdns_success) {
      display.println("mDNS: " MDNS_NAME);
  }
#endif

  display.setTextSize(1);

#if 0
  // Just show responding I2C addresses
  uint8_t addr = 0;
  for (addr = 0; addr <= 0x7F; addr++) {
    Wire.beginTransmission(addr);
    if (Wire.endTransmission() == 0) {
      printHex(addr); display.print(" ");
    }
  }
  display.println();
#else
  display.print("CAP ");
  if (cap_good) {
#if 0
    uint8_t v2;
    cap1214_read(CAP1214_REG_GROUP_STATUS, &v2); printHex(v2);
#endif
#if 0
    uint16_t st = cap1214_read_buttons(false);
    printHex(st >> 8);
    printHex(st & 0xFF);
#endif
    char key[2] = { 0, 0 }; bool prox;
    static char pin[5] = { "____" }; static int pinpos = 0;
    static char last_key = 'Q';
    cap1214_read_key(key, &prox);
    if (key[0] == last_key) {
      /* key is still pressed, ignore */
    } else {
      last_key = key[0];
      if (key[0]!='\0') {
        if (key[0]=='\b') {
          if (pinpos>0) { pinpos--; }
          pin[pinpos] = '_';
        }
        if (pinpos==4 || key[0]=='\r') {
          pin[0]=pin[1]=pin[2]=pin[3]='_'; pinpos=0;
        }
        if (key[0]!='\r' && key[0]!='\b') {
          pin[pinpos++] = key[0];
        }
      }
    }
    display.print(pin);
    if (prox || key[0] != 0) {
      proxDelay.restart();
    }
    if (proxDelay.isExpired()) {
      if (is_awake) {
        // go to sleep: flip polarity to normally-off
        polarity = POLARITY_ASLEEP;
        is_awake = false;
      }
    } else {
      if (!is_awake) {
        // wake up: flip polarity to normally-on
        polarity = POLARITY_AWAKE;
        is_awake = true;
      }
    }
    display.print(proxDelay.isExpired() ? "@" : "!");
#if 0
    cap1214_read(CAP1214_REG_NOISE_STATUS_2, &v2); printHex(v2);
    cap1214_read(CAP1214_REG_NOISE_STATUS_1, &v2); printHex(v2);
#endif
    display.print(" ");
    switch (*key) {
    case '\0': display.print(" "); break;
    case '\r': display.print("ENTER"); break;
    case '\b': display.print("BKSP"); break;
    default: display.print(key); break;
    }
    if (prox) { display.print(" PROX"); }
    display.println();
  } else {
    display.println("not found");
    uint8_t val = 0;
    bool r = cap1214_read(CAP1214_REG_VENDOR_ID, &val);
    display.print(r ? "true " : "false ");
    printHex(val);
    display.println();
  }
#endif
#ifdef RFIDTEST
  if (rfid_good) {
    display.print("RFID: ");
    uint8_t rfid_success;
    uint8_t uid[] = { 0, 0, 0, 0, 0, 0, 0 };  // Buffer to store the returned UID
    uint8_t uidLength;                        // Length of the UID (4 or 7 bytes depending on ISO14443A card type)
    rfid_success = rfid.readPassiveTargetID(PN532_MIFARE_ISO14443A, uid, &uidLength, 100);
    if (rfid_success) {
      display.print(uidLength); display.print(" ");
      for (uint8_t i=0; i<uidLength; i++) {
        printHex(uid[i]);
      }
      display.println();
      if (cap_good) {
        cap1214_write(CAP1214_REG_FEEDBACK_ONESHOT, 0xFF);
      }
    } else {
      display.println("(listening)");
    }
  }
#endif
#ifdef TEMPTEST
  if (tempsensor_good) {
    float f = tempsensor.readTempF();
    display.print("Temp: ");
    display.print(f, 4);
    display.println();
  }
#endif
#ifdef RTCTEST
  if (rtc_good) {
    DateTime now = rtc.now();

    display.print(now.year(), DEC);
    display.print('/');
    display.print(now.month(), DEC);
    display.print('/');
    display.print(now.day(), DEC);
    display.print(" (");
    display.print(daysOfTheWeek[now.dayOfTheWeek()]);
    display.print(") ");
    display.print(now.hour(), DEC);
    display.print(':');
    display.print(now.minute(), DEC);
    display.print(':');
    display.print(now.second(), DEC);
    display.println();

    display.print(" since midnight 1/1/1970 = ");
    display.print(now.unixtime());
    display.print("s = ");
    display.print(now.unixtime() / 86400L);
    display.println("d");

    display.print("Temperature: ");
    display.print(rtc.getTemperature());
    display.println(" C");
  } else {
    display.println("RTC not found");
  }
#endif
#endif
  display.display();
}

void setup() {
  Wire.begin();
  Serial.begin(115200);

  // Wifi Setup
  WiFi.mode(WIFI_STA);
  WiFi.begin(WIFI_SSID, WIFI_PASS);

  // OLED setup
  display.begin(0x3C, true); // Address 0x3C default
  pinMode(BUTTON_A, INPUT_PULLUP);
  pinMode(BUTTON_B, INPUT_PULLUP);
  pinMode(BUTTON_C, INPUT_PULLUP);

  // Clear the buffer.
  display.clearDisplay();
  display.setRotation(1);

  display.setTextSize(1);
  display.setCursor(0,0);

  invertText();
  display.println("Keypad tester");
  normalText();

  display.println("");
  display.print("Connecting to SSID\n" WIFI_SSID ": ");
  display.display();

  // Wait for connection
  while (WiFi.status() != WL_CONNECTED) {
    delay(500);
    Serial.print(".");
  }
  display.clearDisplay();
  display.setCursor(0,0);
  display.print("IP: ");
  display.println(WiFi.localIP());
  display.display();

  Serial.println("");
  Serial.print("Connected to ");
  Serial.println(WIFI_SSID);
  Serial.print("IP address: ");
  Serial.println(WiFi.localIP());

  mdns_success = false;
  if (MDNS.begin(MDNS_NAME)) {
    mdns_success = true;
    Serial.println("MDNS responder started: " MDNS_NAME);
    display.println("mDNS: " MDNS_NAME);
    display.display();
  }

  // Hostname defaults to esp3232-[MAC]
  ArduinoOTA.setHostname(MDNS_NAME);
  ArduinoOTA.setPassword(OTA_PASSWD);
  ArduinoOTA
  .onStart([]() {
    String type;
    digitalWrite(LED_BUILTIN, LOW);
    if (ArduinoOTA.getCommand() == U_FLASH)
      type = "sketch";
    else // U_SPIFFS
      type = "filesystem";

    // NOTE: if updating SPIFFS this would be the place to unmount SPIFFS using SPIFFS.end()
    Serial.println("Start updating " + type);
  });
  ArduinoOTA.onEnd([]() {
    Serial.println("\nEnd");
  });
  ArduinoOTA.onProgress([](unsigned int progress, unsigned int total) {
    Serial.printf("Progress: %u%%\r", (progress / (total / 100)));
  });
  ArduinoOTA.onError([](ota_error_t error) {
    Serial.printf("Error[%u]: ", error);
    if (error == OTA_AUTH_ERROR) Serial.println("Auth Failed");
    else if (error == OTA_BEGIN_ERROR) Serial.println("Begin Failed");
    else if (error == OTA_CONNECT_ERROR) Serial.println("Connect Failed");
    else if (error == OTA_RECEIVE_ERROR) Serial.println("Receive Failed");
    else if (error == OTA_END_ERROR) Serial.println("End Failed");
  });

  ArduinoOTA.begin();

  display.print("IO EXP v");
  int kp_ver = read_keypad_version();
  keypad_hw_v2 = (kp_ver == 2);
  display.println(kp_ver);

#ifdef RTCTEST
  display.print("RTC ");
  rtc_good = rtc.begin();
  display.println(rtc_good ? "good": "not found");
  if (rtc_good && rtc.lostPower()) {
    rtc.adjust(DateTime(F(__DATE__), F(__TIME__)));
  }
#endif /* RTCTEST */

#ifdef TEMPTEST
  display.print("MCP9808 ");
  tempsensor_good = tempsensor.begin(MCP9808_I2CADDR_DEFAULT);
  display.println(tempsensor_good ? "good" : "not found");
  if (tempsensor_good) {
    tempsensor.setResolution(0); // every 30ms, 0.5C resolution
    tempsensor.wake();
  }
#endif /* TEMPTEST */

#ifdef RFIDTEST
  display.print("RFID: ");
  rfid_good = rfid.begin();
  if (rfid_good) {
    uint32_t versiondata = rfid.getFirmwareVersion();
    if (versiondata==0) {
      rfid_good = false;
    }
    display.print("PN5"); printHex((versiondata>>24) & 0xFF);
    display.print(" v"); display.print((versiondata>>16) & 0xFF);
    display.print("."); display.print((versiondata>>8) & 0xFF);
    display.println();
  } else {
    display.println("not found");
  }
#endif

  display.print("CAP ");
  cap_good = cap1214_init();
  display.println(cap_good ? "good": "not found");
  display.display();
#ifdef LONG_WAIT_AFTER_INIT
  delay(5000);
#endif
  is_awake = false;
  proxDelay.restart();
}

void loop() {
    ArduinoOTA.handle();
    MDNS.update();

#ifdef PROXTEST
    /* no update delay, just refresh as fast as possible */
#else
    if (!updateDelay.isExpired()) {
        return;
    }
    updateDelay.restart();
#endif

    updateDisplay();
}

#endif /* KEYTESTER */

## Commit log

2023-07-04 Initial version of OpenEVSE keypad
    [Keypad.kicad_pcb, Keypad.kicad_sch, Keypad.sch]
2023-07-04 Reorg into separate front and back PCB
    This would allow the use of "normal" front-view LEDs, ie UV LEDs
    to exploit the "natural" flourescence of FR4.
    [Keypad-Back.kicad_pcb, Keypad-Back.kicad_sch, Keypad-Back.sch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]
2023-07-05 Back to a one-board design with rear-firing LEDs
    Giving up on the UV LED idea for now.
    [Keypad.kicad_pcb, Keypad.kicad_sch]
2023-07-05 Steady work on Keypad PCB
    [Keypad.kicad_pcb, Keypad.kicad_sch]
2023-07-06 Attempt 2 at routing, cap sensor at bottom
    [Keypad.kicad_pcb, Keypad.kicad_sch]
2023-07-07 Take 3, the JST-XH for the feedback is too large.
    [Keypad.kicad_pcb, Keypad.kicad_sch]
2023-07-08 First version of gerbers
    [Keypad.kicad_pcb]
2023-07-09 Second version, to fix the disconnected touch pad centers
    Tried to get JLCPCB to adopt this, but apparently unsuccessfully.
    [Keypad.kicad_pcb]
2023-07-10 Third version, no vias to cast shadows.
    Also add the BOM.
    [Keypad.csv, Keypad.kicad_pcb]
2023-09-06 Fix schematic and PCB
    1. Swap LED6 and LED11 so that the dual LED is on the high-power port.
    (This change isn't green-wired on the existing boards.)
    2. Add 47pF series cap to TOUCH_GUARD to bring it into spec.
    (Measured at 80pF; CAP1214 supports 50pF max.)
    3. Fix RESET -- it should be grounded, not tied high.
    [Keypad.kicad_pcb, Keypad.kicad_sch]
2023-09-07 Fix handling of zero key (CS8) which has a weird press-and-hold feature
    [keytester.cpp]
2023-09-25 Fix some errors in original boards; add RFID functionality
    [AN144411.xls, Keypad.kicad_pcb, Keypad.kicad_sch]
2023-10-21 Relocate traces for keypad 2/5/8 which got moved somehow
    [Keypad.csv, Keypad.kicad_pcb]
2023-10-23 Ensure that all CAP1214 sensors are turned on
2023-10-24 Add PCA9536 I/O expander to handle LED12 and hardware version detect
    [Keypad.kicad_pcb, Keypad.kicad_sch]
2023-10-25 Simplify schematic and PCB
    Remove the solder jumper for SEL0/SEL1, that's been tested & is correct.
    Add 0-ohm resistors for GPIO expander to accomodate future green wire hacks.
    Mark the DNP components on the schematic.
    [Keypad.kicad_pcb, Keypad.kicad_sch]
2024-01-31 Add some .gitignored files to Keypad-Back
    I don't think these are actually necessary, but I'm about to delete
    this subdirectory in the next commit so I figured I'd stick them in
    the repo just in case.
2024-01-31 Remove "Keypad Back"
    This directory was left over from "revision 0" of the design, when
    the forward-shining UV LEDs were mounted on a separate PCB separated
    from the main board with 4-pin headers.
    [Keypad-Back.kicad_pcb, Keypad-Back.kicad_sch, Keypad-Back.sch]
2024-01-31 Add Keypad-Ext
    This was a temporary bodge board for the Revision 2 hardware, which added
    a PCA9536 I/O expander to allow LED12 to be driven separately. Also
    the presence of PCA9536 on the I2C bus was also an indicator we were
    running on "revision 2" hardware, which had some of the capacitive
    sense lines moved around compare to revision 1 hardware.
    In the end I didn't end up using these files; I redrew the schematic
    using EasyEDA in order to try out JLCPCB's PCBA service for the first
    time. But the schematic here is the same as the one I redrew and had
    fabricated.
    [Keypad-Ext.kicad_pcb, Keypad-Ext.kicad_sch, Keypad-Ext.sch]
2024-02-01 Remove Keypad-Ext bodge board -- unnecessary for Revision 3 hardware
    [Keypad-Ext.kicad_pcb, Keypad-Ext.kicad_sch, Keypad-Ext.sch]
2024-02-01 More schematic cleanup
    * Remove silkscreen for R23/R24, which are shorted jumpers as a netlist
    hack for the PCB antenna, not "real" components.
    * Remove unnecessary R15 (and its traces) now that we have PCA9536 to
    drive LED12.
    [Keypad.kicad_pcb, Keypad.kicad_sch]
2024-02-01 Add schematic PDF for easy browsing
2024-02-01 More work on schematic and gerbers; fill out BOM with JLCPCB part #s
    Also updated the README a bit.
    [Keypad.kicad_pcb, Keypad.kicad_sch]
2024-02-01 Add STL for LCD mount
    [lcd-trim-more.scad]
2024-02-02 RFID tuning
    Tuned the length of the TX1 and TX2 traces to maintain symmetry; moved
    L1/L2 around a bit to the same end. Added a zero-ohm resistor so we
    can disconnect the antenna "virtual ground" from the actual ground,
    as recommended by the AN1445 app note.
    [Keypad.kicad_pcb, Keypad.kicad_sch]
2024-02-03 Add missing LCD mount stl files
    [LCD_fixed.stl, lcd-trim-more.stl]
